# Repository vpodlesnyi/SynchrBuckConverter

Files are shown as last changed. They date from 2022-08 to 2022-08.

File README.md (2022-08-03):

# SynchrBuckConverter
The PCB of a synchronous buck converter with power delivery up to 7.5kW.

Technical specifications:
- input voltage up to 310 V;
- output voltage is 48 V;
- output current up to 160 Amps;
- isolated feedback nets;
- negative gate driver bias;
- isolated gate drivers. 

demo image

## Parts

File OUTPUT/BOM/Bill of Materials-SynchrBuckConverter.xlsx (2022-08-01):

Description | Part Number | Value | Voltage | Designator | Quantity
DC/DC преобразователь | MGJ2D051505SC |  |  | DD1, DD2, DD3, DD4 | 4
EMI Suppression Filter | HF467-200M-65AV | 18мкГн |  | L1, L2 | 2
HIGH-DRIVE OPERATIONAL AMPLIFIERS WITH SHUTDOWN | LMV321ILT |  |  | DA5 | 1
N-MOSFET | IXFX120N65X2 |  |  | VT1, VT2, VT3, VT4 | 4
Single Channel MOSFET Gate Driver IC | 1EDI60N12AFXUMA1 |  |  | DA1, DA2, DA3, DA4 | 4
Конденсатор | GRM43DR72J104KW01L | 0,1мк | 630В | C1, C2, C13, C15 | 4
Конденсатор | GRM1555C1H102J | 1000 | 50B | C3 | 1
Конденсатор | GRM188R71C105KA12D** | 1мк | 16B | C4, C5, C6, C7, C8 | 5
Конденсатор | GRM155R71H104KE14D | 0,1мк | 50В | C9, C10, C11, C12 | 4
Конденсатор | GRM155R71H104KE14D | 0,1мк | 50В | C14 | 1
Конденсатор | GRM1535C1H100J | 10 | 50B | C16, C17 | 2
Конденсатор | GRM21BR71H105K | 1мк | 50B | C18, C19, C20, C21, C22, C23, C24, C25 | 8
Конденсатор | GRM31CR72E104K | 0,1мк | 250В | C30, C31, C34 | 3
Конденсатор | GRM31CR72E473K | 0,047мк | 250В | C32, C33 | 2
Конденсатор | C3225X7R1H106K250AC | 10мк | 50В | C35, C36, C37, C38 | 4
Конденсатор полярный | EEV-EB2D101M | 100мк | 200В | C26, C27, C28, C29 | 4
Разъем - 3 конт. розетка | 559320310 |  |  | X3 | 1
Разъем - 4 конт. розетка | 430450412 |  |  | X4 | 1
Разъем - 4 конт. розетка | 430450412 |  |  | X5 | 1
Разъем - 4 конт. розетка | 430450412 |  |  | X8 | 1
Разъем - 5 конт. розетка | 559320510 |  |  | X1, X2 | 2
Разъем - 6 конт. розетка | 1723161106 |  |  | X6 | 1
Разъем - 6 конт. розетка | 1722981106 |  |  | X7 | 1
Резистор | RC0402FR-0710KL | 10к |  | R1, R2, R3, R4, R5, R6 | 6
Резистор | RC0402FR-071KL | 1к |  | R7, R8, R17, R22, R23 | 5
Резистор | RC0603FR-075R1L | 5,1 |  | R9, R11, R13, R15 | 4
Резистор | RC0603FR-073R3L | 3,3 |  | R10, R12, R14, R16 | 4
Резистор | RC0603FR-071KL | 1к |  | R18, R19, R20, R21 | 4
Резистор | RC2512FR-075K1 | 5,1к |  | R24 | 1
Резистор | RC2512FR-07330RL | 330 |  | R25 | 1

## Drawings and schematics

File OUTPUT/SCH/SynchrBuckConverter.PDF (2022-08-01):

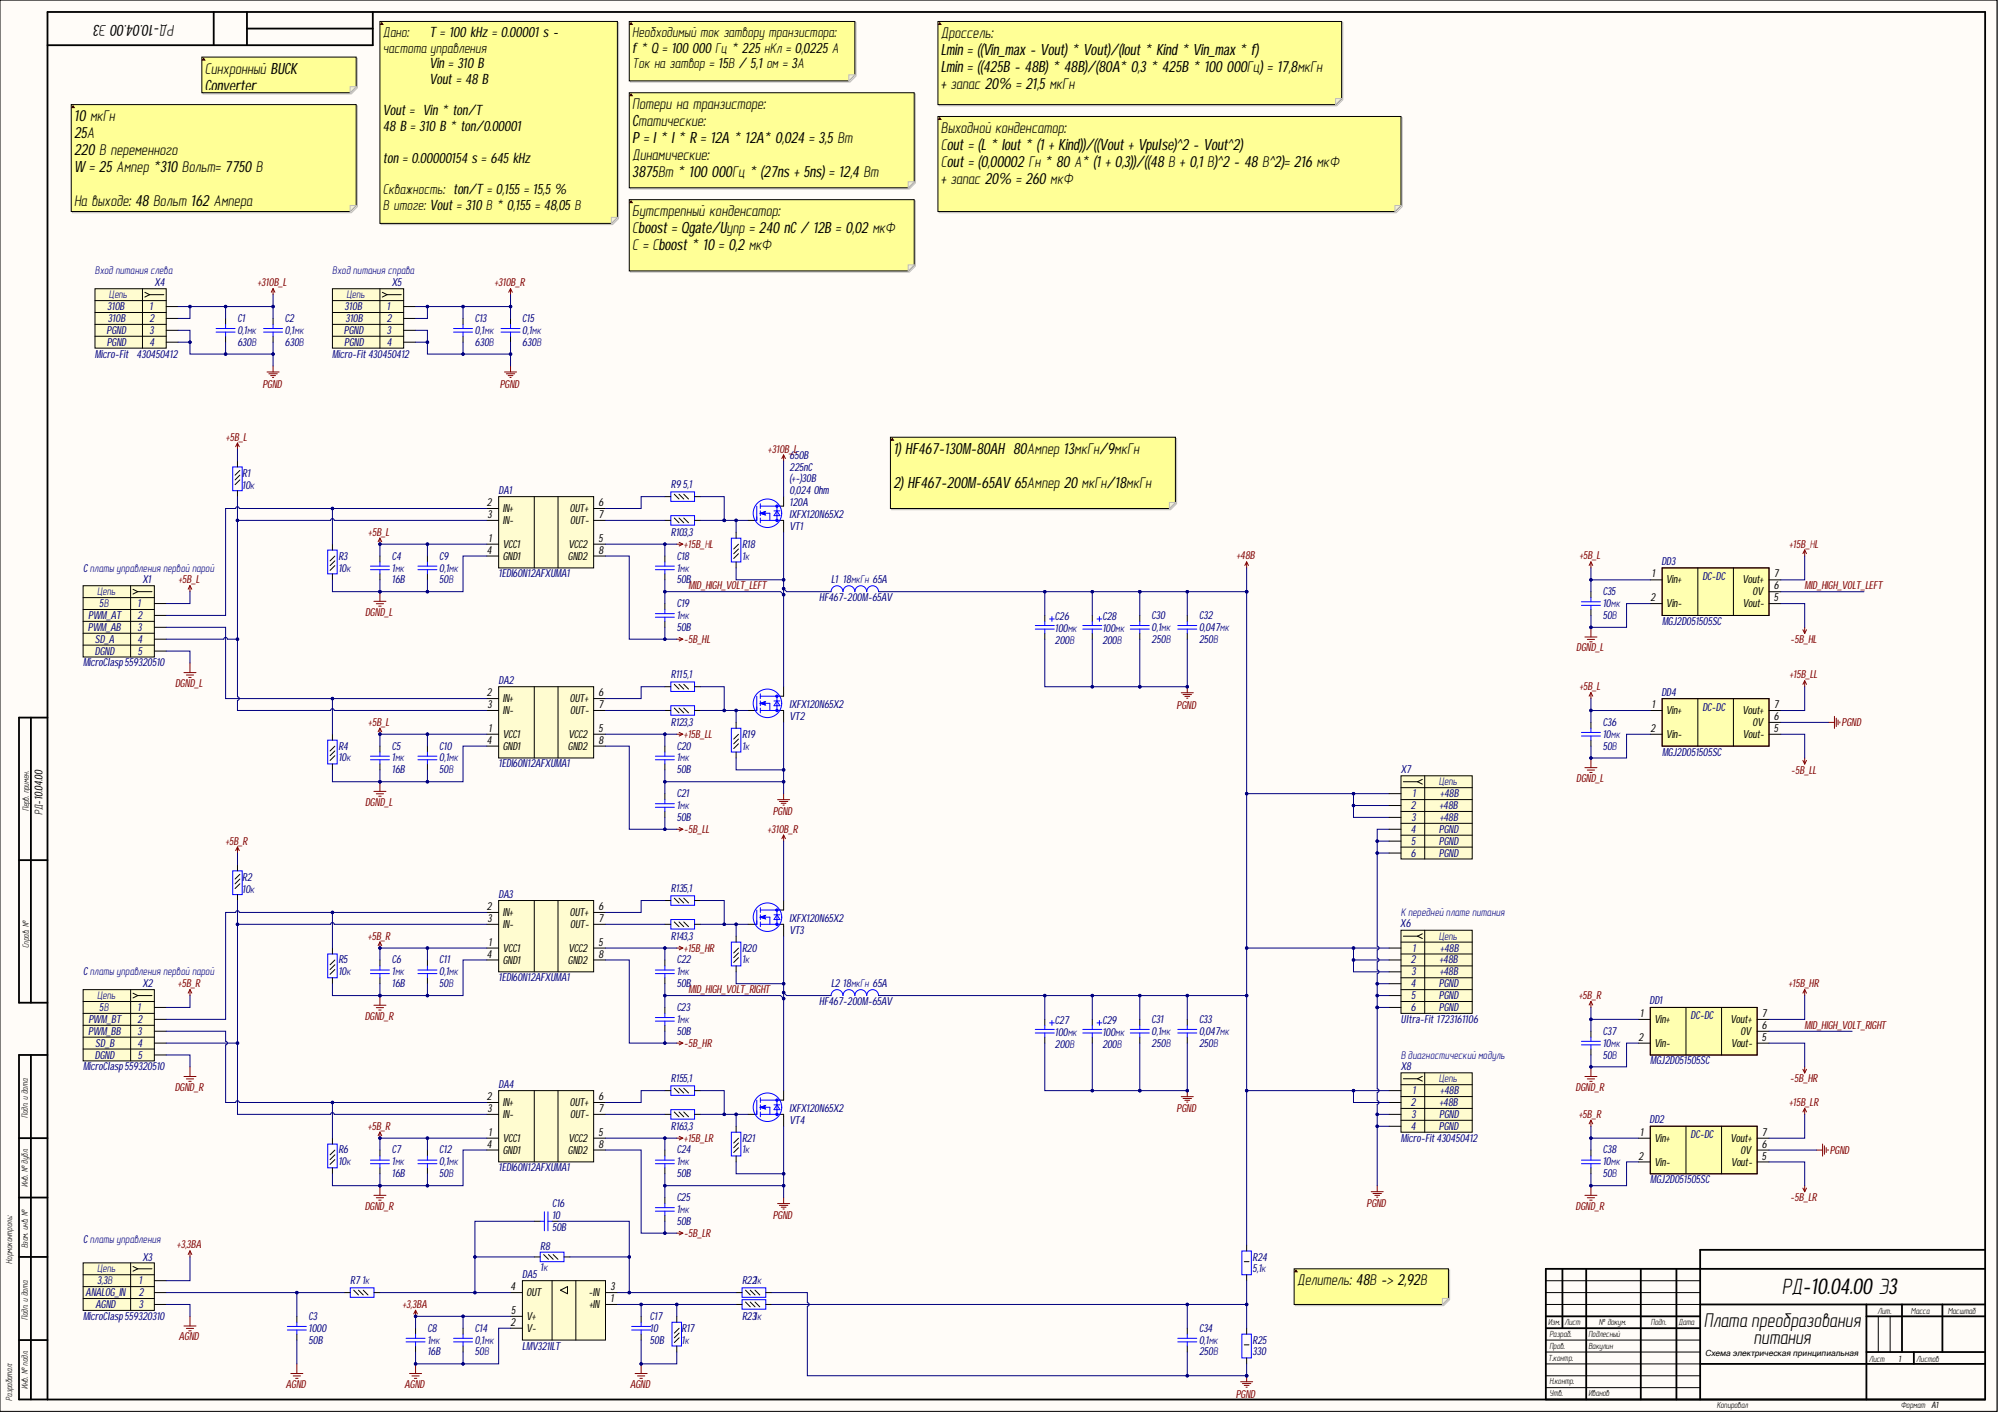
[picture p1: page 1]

Необходимый ток затвору транзистора:
f * Q = 100 000 Гц * 225 нКл = 0,0225
Ток на затвор = 15В / 5,1 ом = 3А

Дроссель
Lmin = ((Vin_max - Vout) * Vout)/(Iout * Kind * Vin_max * f)
Lmin = ((425B - 48B) * 48B)/(80A* 0,3 * 425B * 100 000Гц) = 17,8мкГн
+ запас 20% = 21,5 мкГн

Выходной конденсатор
Сout = (L * Iout * (1 + Kind))/((Vout + Vpulse)^2 - Vout^2) Сout = (0,00002 Гн * 80 А* (1 + 0,3))/((48 В + 0,1 В)^2 - 48

Скважность: ton/T = 0,155 = 15,5 % В итоге: Vout = 310 В * 0,155 = 48,05

На выходе: 48 Вольт 162 Ампера

Бутстрепный конденсатор
Сboost = Qgate/Uупр = 240 nC / 12B = 0,02 мкФ С = Сboost * 10 = 0,2 мкФ

IN+ IN-VCC1 GND1 | OUT-

Vin- | DC-DC | Vout+ 0V Vout- | MID_HIGH_VOLT_LEFT Vin+

Цепь
PWM_AT | 1234
5В

PWM_AB
SD_A
DGND | 5

Инв. № подл. Инв. № дубл. Подп. и дата Взам. инв. № Подп. и дата Перв. примен. Справ. №

+48B

PGND
5 | PGND 6 PGND

PWM_BT | 1234

PWM_BB
SD_B

MicroClasp559320310 X3 3,3В | 12

ANALOG_IN
AGND | 3

OUT | -IN

Плата преобразования питания Схема электрическая принципиальная | Лит

Пров . | Вакулин
Т.контр . | | Лис т | Листов

Н.контр .
Утв . | Иванов

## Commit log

2022-08-01 Uploaded files.
    [Bill of Materials-SynchrBuckConverter.xlsx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]
2022-08-02 Eidted the SCH list.
    [SynchrBuckConverter.SchDoc]
